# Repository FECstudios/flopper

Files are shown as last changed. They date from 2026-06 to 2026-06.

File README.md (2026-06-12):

# Flopper
**A physical study tracker that lives on your desk, not your phone.**



🎥 Demo: https://youtube.com/shorts/d5FyO_5jDAI

We built Flopper because we kept losing track of how long we actually studied vs. how long we *thought* we studied. It's a small 3D-printed device with an OLED screen, a rotary encoder, and an IMU sensor. Shake it to start a session, rotate the encoder to switch between modes (study, coding, break, etc.), and open a browser to see your stats on a dashboard the ESP32 hosts itself — no internet, no app, no account.

Three 14-year-olds from Turkey made this. It fits in your palm.

---

## Gallery

<p align="center">
  
  
  
</p>

---

## What it does

- Shake the device (or click the encoder) → session starts
- Rotate the encoder → switch activity mode
- Timer runs, buzzer goes off when time's up → shake again to dismiss
- Open `192.168.x.x` on any device on the same Wi-Fi → see your session history live

### Modes
Study · Coding · Reading · Break · Exercise · Free Time

---

## Hardware

| Component | What it's for |
|---|---|
| Seeed Studio XIAO ESP32-C6 | Runs everything, hosts the web server |
| MPU6050 (GY-521) | Detects shakes and tilts |
| 1.3" SH1106 OLED | Shows the current mode and timer |
| Rotary encoder | Scroll through modes, click to start |
| Buzzer | Alarm when session ends |
| 1S LiPo | Battery power |

---

## How it works

The MPU6050 constantly reads acceleration. When it detects a shake above a threshold, it starts the timer for whatever mode is selected. The rotary encoder lets you scroll through modes on the OLED before you start — or you can just click it instead of shaking if you want.

When the session ends, the buzzer fires. Shake or click to stop it.

The ESP32 runs a small web server over Wi-Fi. Once it connects to your network it shows its local IP on the OLED. Open that in a browser and you get a dashboard with your session history and time per mode.

---

## Setup

**You'll need:**
- Arduino IDE 2.x
- ESP32 board package
- Libraries: `Adafruit SH110X`, `MPU6050_light`, `ESPAsyncWebServer`

**Steps:**
1. Clone the repo
2. Open `flopper/codes/online.ino` or `flopper/codes/offline.ino`
3. Change the Wi-Fi credentials near the top if you prefer the online version:
   ```cpp
      const char* ssid = "YOUR_SSID";             
      const char* wifiPassword = "YOUR_PASSWORD"; 
   ```
4. Flash to XIAO ESP32-C6
5. IP address shows on the OLED once it connects — open it in a browser

---

## Why we made it

We wanted something physical. Every productivity app we tried was on the same device we were trying to avoid. With Flopper you just pick it up and shake it — that's the whole interaction. No screen to unlock, no notifications to scroll past.

Also we wanted to see if we could fit a display, motion sensor, encoder, Wi-Fi, and battery into something 3D-printed that actually looked decent.

---

## Roadmap

- [ ] Daily streaks
- [ ] Better analytics on the dashboard
- [ ] OTA updates
- [ ] Achievement system

---

## License

[Apache 2.0](LICENSE)

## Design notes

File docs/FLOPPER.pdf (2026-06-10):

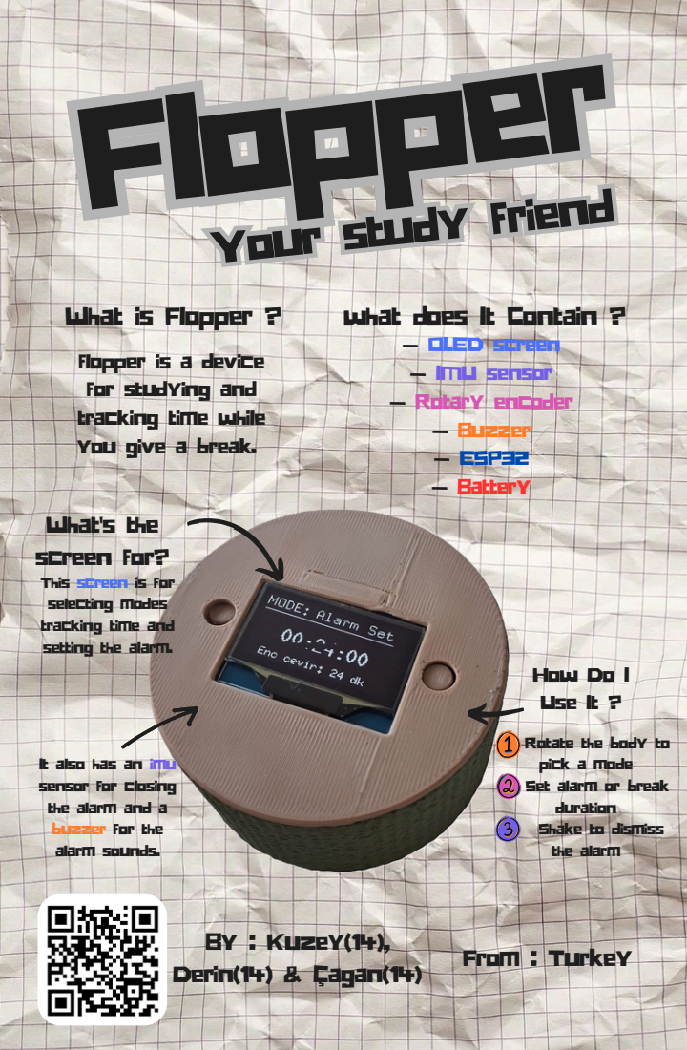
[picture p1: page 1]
By : Kuzey(14), Derin(14) & Çagan(14); From : Turkey; How Do I Use It ?

Flopper Flopper Flopper

Your study friend Your study friend Your study friend

What is Flopper ?

what does It Contain ?
— OLED screen
— IMU sensor
— Rotary encoder
— Buzzer
— ESP32
— Battery

flopper is a device
for studying and
tracking time while
you give a break.

What's the
screen for?
This screen is for
selecting modes
tracking time and
setting the alarm.

Rotate the body to
pick a mode
Set alarm or break
duration
Shake to dismiss
the alarm

It also has an imu
sensor for closing
the alarm and a
buzzer for the
alarm sounds.

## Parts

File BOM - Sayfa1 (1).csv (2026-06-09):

Part name | Quantity | Price | Link
XIAO ESP32C6 | 1 | 372,15TL | https://www.e-komponent.com/xiao-esp32c6-113991254
Buzzer | 1 | 8,83TL | https://www.robo90.com/pasif-buzzer-5v
Rotary Encoder Module | 1 | 36,70TL | https://www.robocombo.com/Arduino-Rotary-Encoder-Modulu
25x35 Lipo Battery | 1 | 699TL | https://www.trendyol.com/genel-markalar/25x35mm-lipo-pil-600mah-35x25mm-lipo-pil-602535-3-7v-lipo-pil-602535-3-7v-polimer-pil-bensu-pendik-p-824317653
1.3 inch oled screen | 1 | 152,30TL | https://www.voltaj.net/13-inch-i2c-oled-ekran-128x64-ssd1106g-pmu35378
MPU 6050 | 1 | 102,49TL | https://www.robitshop.com/urun/6-eksen-ivme-ve-gyro-sensoru-mpu6050-gy-521
M3 screw | 4 | 1,30TL | https://www.robotistan.com/m3-25mm-yildiz-basli-civata?language=tr&h=054a82bc
M3 hexnut | 1 | 10,80TL | https://www.robolinkmarket.com/m3-somun-10-adet

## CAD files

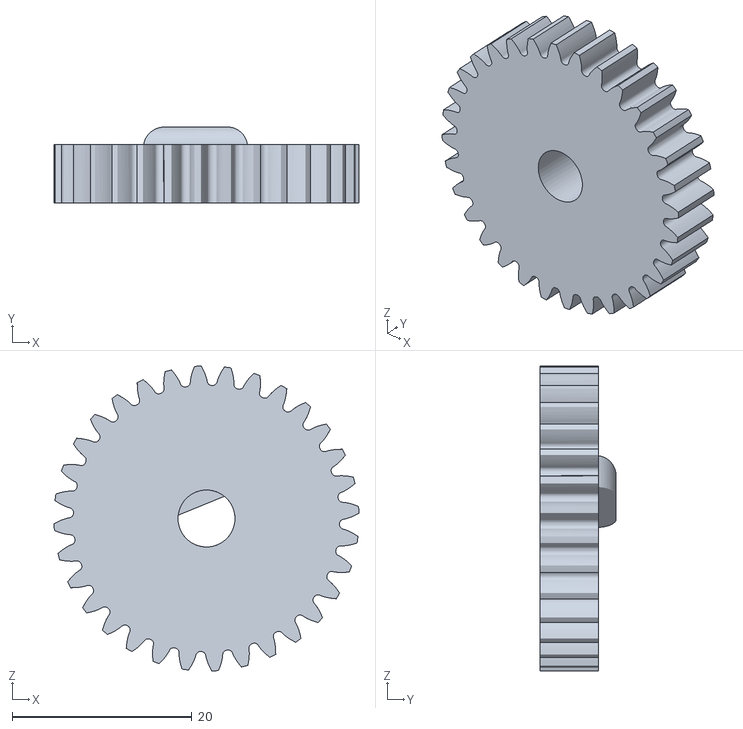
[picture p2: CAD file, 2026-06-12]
3dprintfiles/gear.stl
34.0 x 8.48 x 34.0

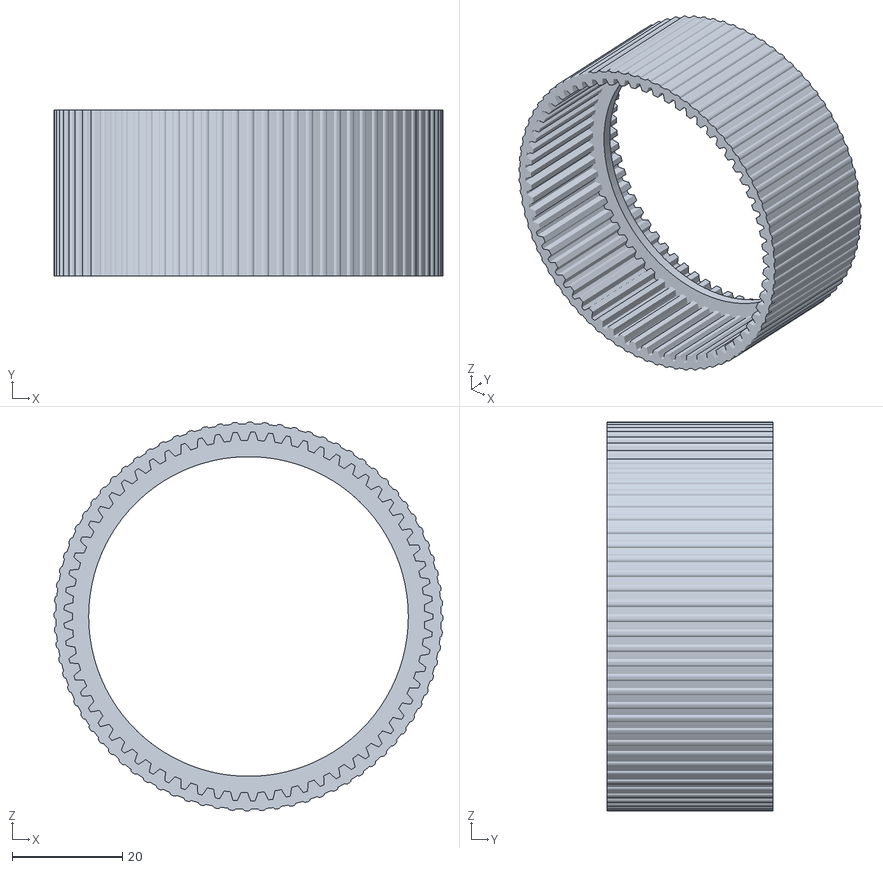
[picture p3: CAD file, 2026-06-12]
3dprintfiles/outter.stl
70.6 x 30.2 x 70.6

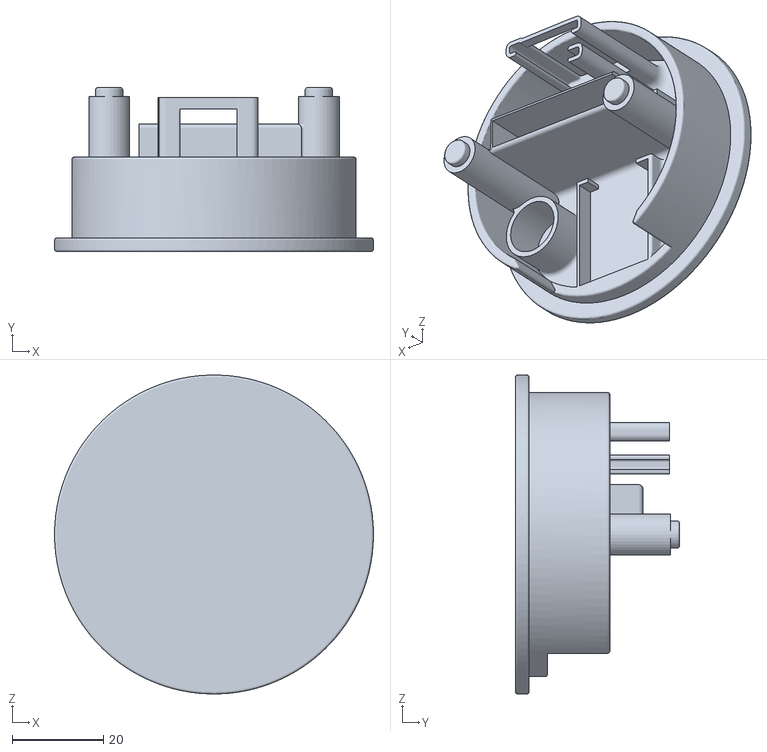
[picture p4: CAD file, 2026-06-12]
3dprintfiles/inner.stl
70.0 x 36.0 x 70.0

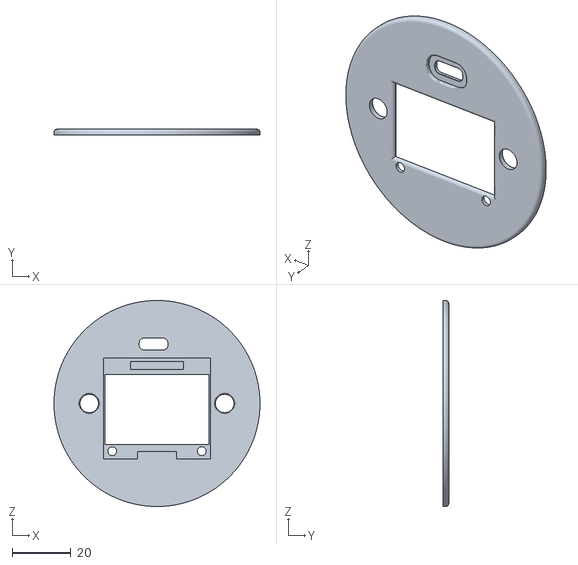
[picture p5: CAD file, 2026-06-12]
3dprintfiles/top.stl
70.0 x 1.90 x 70.0

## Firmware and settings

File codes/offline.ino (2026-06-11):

#include <U8g2lib.h>
#include <Wire.h>
#include <MPU6050_light.h>
#include <RotaryEncoder.h>
#include <Preferences.h>

MPU6050 mpu(Wire);
U8G2_SH1106_128X64_NONAME_F_HW_I2C u8g2(U8G2_R0, U8X8_PIN_NONE);

#define CLK_PIN D0 
#define DT_PIN  D1 

RotaryEncoder encoder(CLK_PIN, DT_PIN, RotaryEncoder::LatchMode::FOUR3);
Preferences preferences;

// --- Pomodoro Settings ---
int pomodoroWork = 25;
int pomodoroShortBreak = 5;
int pomodoroLongBreak = 15;
int pomodoroCycles = 4;

int currentPomodoroCycle = 1;
bool isPomodoroBreak = false;
long pomodoroRemainingSec = 25 * 60;
long pomodoroElapsedSec = 0;

// --- Time Tracking Variables ---
long totalStudySec = 0;      
long sessionStudySec = 0;    
long distractionSec = 0;     

long tytElapsedSec = 0;
long aytElapsedSec = 0;

// --- Other Global Variables ---
float accelX, accelY, accelZ;
float gyroX, gyroY, gyroZ;

int currentMode = 1;  
const char* modeNames[] = {"", "STUDY", "DISTRACT", "ALARM SET", "TYT EXAM", "AYT EXAM", "POMODORO", "STATISTICS"};

bool timerRunning = false;
bool alarmSetModeActive = false;  
bool tiltTriggered = false; 

unsigned long lastSecondTime = 0;
unsigned long lastTapTime = 0;
unsigned long lastShakeTime = 0; 
unsigned long lastSaveTime = 0;
unsigned long lastSetModeActivityTime = 0; 

// For factory reset via upside-down gesture
unsigned long upsideDownStartTime = 0;
bool isUpsideDown = false;

float tapThreshold = 1.9;  
float shakeThreshold = 3.0; 

int  alarmSetMinutes = 25;    
long alarmRemainingSec = 25 * 60;
long tytRemainingSec = 165 * 60;
long aytRemainingSec = 180 * 60;  
unsigned long lastScreenTime = 0;

// --- Function Prototypes ---
void calibrateSensors();
void readSensors();
void detectTap();
void detectTilt(); 
void detectShake(); 
void detectUpsideDownReset(); 
void updateTimers();
void drawPageDots();
void resetAllData(); 
String formatTime(long totalSeconds);

void setup() {
  Serial.begin(115200);  
  Wire.begin(22, 23);  
  u8g2.begin();
  
  pinMode(CLK_PIN, INPUT_PULLUP);
  pinMode(DT_PIN, INPUT_PULLUP);
  
  byte status = mpu.begin();
  if (status != 0) {
    while (1) {
      u8g2.clearBuffer();
      u8g2.setFont(u8g2_font_8x13_mr);
      u8g2.drawStr(0, 15, "NO SENSOR!");
      u8g2.sendBuffer();
      delay(1000);
    }
  }
  
  calibrateSensors();
  
  // Load data from persistent memory
  preferences.begin("study-data", true);
  totalStudySec = preferences.getULong("totalStudy", 0);
  distractionSec = preferences.getULong("distTime", 0); 
  tytElapsedSec = preferences.getULong("tytTime", 0);
  aytElapsedSec = preferences.getULong("aytTime", 0);
  pomodoroElapsedSec = preferences.getULong("pomTime", 0);
  pomodoroWork = preferences.getInt("pomWork", 25);
  pomodoroShortBreak = preferences.getInt("pomShort", 5);
  pomodoroLongBreak = preferences.getInt("pomLong", 15);
  pomodoroCycles = preferences.getInt("pomCycles", 4);
  preferences.end();
  
  sessionStudySec = 0; 
  
  pomodoroRemainingSec = pomodoroWork * 60;
  alarmRemainingSec = alarmSetMinutes * 60;
  
  delay(1000);
}

void loop() {
  readSensors();      
  detectTap(); 
  detectTilt(); 
  detectShake(); 
  detectUpsideDownReset(); 
  
  encoder.tick();
  int direction = (int)(encoder.getDirection());

  if (direction != 0) {
    if (timerRunning) {
      Serial.println("-> Timer is running! Mode cannot be changed.");
    }  
    else {
      if (currentMode == 3 && alarmSetModeActive) {
        if (direction < 0) alarmSetMinutes++;
        else alarmSetMinutes--;
        
        if (alarmSetMinutes < 1) alarmSetMinutes = 1;
        if (alarmSetMinutes > 180) alarmSetMinutes = 180;
        
        alarmRemainingSec = (long)alarmSetMinutes * 60;
        lastSetModeActivityTime = millis(); 
        
      } else {
        if (direction < 0) currentMode++;
        else currentMode--;
        
        if (currentMode < 1) currentMode = 1;
        if (currentMode > 7) currentMode = 7; 

        alarmSetModeActive = false;  
        Serial.print("-> New Mode: "); Serial.println(currentMode);
      }
    }
  }

  updateTimers();

  // Save to persistent memory every 60 seconds
  if (millis() - lastSaveTime > 60000) {
      lastSaveTime = millis();
      preferences.begin("study-data", false);
      preferences.putULong("totalStudy", totalStudySec);
      preferences.putULong("distTime", distractionSec); 
      preferences.putULong("tytTime", tytElapsedSec);
      preferences.putULong("aytTime", aytElapsedSec);
      preferences.putULong("pomTime", pomodoroElapsedSec);
      preferences.end();
  }

  // --- OLED DRAWING AREA ---
  if (millis() - lastScreenTime > 150) {
    lastScreenTime = millis();
    u8g2.clearBuffer();

    // 1. MODE NAME (Centered at the top, no uptime text anymore)
    u8g2.setFont(u8g2_font_8x13_mr);
    int textWidth = strlen(modeNames[currentMode]) * 8; 
    u8g2.drawStr((128 - textWidth) / 2, 10, modeNames[currentMode]);
    
    u8g2.drawLine(0, 16, 128, 16); 

    // 2. STATISTICS SCREEN (Mode 7)
    if (currentMode == 7) {
        u8g2.setFont(u8g2_font_6x10_tf);
        u8g2.drawStr(0, 30, "Total  :");
        u8g2.drawStr(70, 30, formatTime(totalStudySec).c_str());
        
        u8g2.drawStr(0, 40, "Distrct:");
        u8g2.drawStr(70, 40, formatTime(distractionSec).c_str());
        
        u8g2.drawStr(0, 50, "TYT    :");
        u8g2.drawStr(70, 50, formatTime(tytElapsedSec).c_str());
        
        u8g2.drawStr(0, 60, "AYT    :");
        u8g2.drawStr(70, 60, formatTime(aytElapsedSec).c_str());
        
        u8g2.sendBuffer();
        return; 
    }

    // 3. TIMER DISPLAY (Modes 1 to 6)
    long hours = 0, minutes = 0, seconds = 0;

    if (currentMode == 1) {  
      hours = sessionStudySec / 3600;
      minutes = (sessionStudySec % 3600) / 60;
      seconds = sessionStudySec % 60;
    }  
    else if (currentMode == 2) { 
      hours = distractionSec / 3600;
      minutes = (distractionSec % 3600) / 60;
      seconds = distractionSec % 60;
    }
    else if (currentMode == 3) {  
      hours = alarmRemainingSec / 3600;
      minutes = (alarmRemainingSec % 3600) / 60;
      seconds = alarmRemainingSec % 60;
    }
    else if (currentMode == 4) {  
      hours = tytRemainingSec / 3600;
      minutes = (tytRemainingSec % 3600) / 60;
      seconds = tytRemainingSec % 60;
    }
    else if (currentMode == 5) {  
      hours = aytRemainingSec / 3600;
      minutes = (aytRemainingSec % 3600) / 60;
      seconds = aytRemainingSec % 60;
    }
    else if (currentMode == 6) { 
      hours = pomodoroRemainingSec / 3600;
      minutes = (pomodoroRemainingSec % 3600) / 60;
      seconds = pomodoroRemainingSec % 60;
    }

    if (currentMode != 7) { 
      u8g2.setFont(u8g2_font_10x20_tn);  
      u8g2.setCursor(24, 40);
      
      if (hours < 10) u8g2.print("0"); u8g2.print(hours); u8g2.print(":");
      if (minutes < 10) u8g2.print("0"); u8g2.print(minutes); u8g2.print(":");
      if (seconds < 10) u8g2.print("0"); u8g2.print(seconds);
      
      u8g2.setFont(u8g2_font_6x10_tf);
      if (timerRunning) {
        if (currentMode == 6) {
            u8g2.drawStr(32, 55, isPomodoroBreak ? "[ BREAK ]" : "[ WORK ]");
        } else {
            u8g2.drawStr(32, 55, "[ RUNNING ]");
        }
      } else {
        if (currentMode == 3) {
          if (alarmSetModeActive) {
            u8g2.setCursor(10, 55);
            u8g2.print("[SET] "); u8g2.print(alarmSetMinutes); u8g2.print(" min");
          } else {
            u8g2.drawStr(0, 55, "Tilt:Set Shake:Reset"); 
          }
        } else if (currentMode == 6) {
            u8g2.drawStr(0, 55, "Tap:Start Shake:Reset"); 
        } else if (currentMode == 4 || currentMode == 5) {
            u8g2.drawStr(15, 55, "Shake -> Reset"); 
        } else if (currentMode == 1) {
            u8g2.drawStr(0, 55, "Tap:Start Shake:Reset Sess."); 
        } else if (currentMode == 2) {
            u8g2.drawStr(0, 55, "Tap:Start Shake:Reset Time"); 
        } else {
          u8g2.drawStr(35, 55, "[ PAUSED ]");
        }
      }
    }  

    drawPageDots();
    u8g2.sendBuffer();
  }
}

void drawPageDots() {
  u8g2.setFont(u8g2_font_6x10_tf);  
  int startX = 36; 
  int yCoord = 63;  

  for (int i = 1; i <= 7; i++) {
    u8g2.setCursor(startX + ((i - 1) * 9), yCoord);  
    if (i == currentMode) {
      u8g2.print((char)183);  
    } else {
      u8g2.print(".");  
    }
  }
}

void updateTimers() {
  if (timerRunning && (millis() - lastSecondTime >= 1000)) {
    lastSecondTime = millis();
    
    if (currentMode == 1) {
        sessionStudySec++;
        totalStudySec++; 
    }  
    else if (currentMode == 2) {
        distractionSec++; 
    }
    else if (currentMode == 3) {
      if (alarmRemainingSec > 0) alarmRemainingSec--;
      else timerRunning = false;  
    }
    else if (currentMode == 4) {
      if (tytRemainingSec > 0) {
          tytRemainingSec--;
          tytElapsedSec++;
      } else timerRunning = false;  
    }
    else if (currentMode == 5) {
      if (aytRemainingSec > 0) {
          aytRemainingSec--;
          aytElapsedSec++;
      } else timerRunning = false;  
    }
    else if (currentMode == 6) { 
        if (pomodoroRemainingSec > 0) {
            pomodoroRemainingSec--;
            pomodoroElapsedSec++;
        } else {
            if (isPomodoroBreak) {
                isPomodoroBreak = false;
                currentPomodoroCycle++;
                if (currentPomodoroCycle > pomodoroCycles) {
                    currentPomodoroCycle = 1; 
                    timerRunning = false;
                } else {
                    pomodoroRemainingSec = pomodoroWork * 60; 
                }
            } else {
                isPomodoroBreak = true;
                if (currentPomodoroCycle % pomodoroCycles == 0) {
                    pomodoroRemainingSec = pomodoroLongBreak * 60; 
                } else {
                    pomodoroRemainingSec = pomodoroShortBreak * 60; 
                }
            }
        }
    }
  }
}

void calibrateSensors() {
  u8g2.clearBuffer();
  u8g2.setFont(u8g2_font_8x13_mr);
  u8g2.drawStr(0, 15, "CALIBRATING...");
  u8g2.sendBuffer();
  delay(600);
  mpu.calcOffsets(true, true);  
  u8g2.clearBuffer();
  u8g2.drawStr(0, 15, "COMPLETE");
  u8g2.sendBuffer();
}

void readSensors() {
  mpu.update();
  accelX = mpu.getAccX();
  accelY = mpu.getAccY();
  accelZ = mpu.getAccZ();
  gyroX = mpu.getGyroX();
  gyroY = mpu.getGyroY();
  gyroZ = mpu.getGyroZ();
}

void detectTap() {
  float deviation = abs(accelZ - 1.0);
  if (deviation > tapThreshold) {
    if (millis() - lastTapTime > 600) {  
      timerRunning = !timerRunning;  
      lastTapTime = millis();
      lastSecondTime = millis();  
    }
  }
}

void detectTilt() {
  if (currentMode == 3 && !timerRunning) {
    float tiltMagnitude = abs(accelX) + abs(accelY);
    
    if (tiltMagnitude > 0.7) { 
      if (!tiltTriggered) {
        tiltTriggered = true;
        alarmSetModeActive = !alarmSetModeActive;
        lastSetModeActivityTime = millis(); 
      }
    } 
    else if (tiltMagnitude < 0.3) {
      tiltTriggered = false; 
    }

    if (alarmSetModeActive && (millis() - lastSetModeActivityTime > 5000)) {
      alarmSetModeActive = false;
      tiltTriggered = false; 
    }
  }
}

void detectShake() {
  if (currentMode == 1 || currentMode == 2 || currentMode == 3 || currentMode == 4 || currentMode == 5 || currentMode == 6) {
    float totalAccel = sqrt(accelX * accelX + accelY * accelY + accelZ * accelZ);
    
    if (totalAccel > shakeThreshold && (millis() - lastShakeTime > 1000)) {
      lastShakeTime = millis();
      
      if (currentMode == 1) sessionStudySec = 0; 
      else if (currentMode == 2) distractionSec = 0; 
      else if (currentMode == 3) {
        alarmRemainingSec = alarmSetMinutes * 60;
        timerRunning = false; 
      }
      else if (currentMode == 4) {
        tytRemainingSec = 165 * 60;
        timerRunning = false;
      }
      else if (currentMode == 5) {
        aytRemainingSec = 180 * 60;
        timerRunning = false;
      }
      else if (currentMode == 6) {
        pomodoroRemainingSec = pomodoroWork * 60;
        isPomodoroBreak = false;
        currentPomodoroCycle = 1;
        timerRunning = false;
      }
      Serial.println("-> SHAKE DETECTED! Current mode timer reset.");
    }
  }
}

void detectUpsideDownReset() {
  // Device is upside down when Z axis is approximately -1.0
  if (accelZ < -0.7) { 
    if (!isUpsideDown) {
      isUpsideDown = true;
      upsideDownStartTime = millis();
    } else {
      // If held upside down for 5 seconds (5000 ms)
      if (millis() - upsideDownStartTime > 5000) {
        resetAllData();
        isUpsideDown = false; // Reset trigger after action
      }
    }
  } else {
    isUpsideDown = false; // Cancel if device is righted
  }
}

void resetAllData() {
  // 1. Clear persistent memory
  preferences.begin("study-data", false);
  preferences.putULong("totalStudy", 0);
  preferences.putULong("distTime", 0);
  preferences.putULong("tytTime", 0);
  preferences.putULong("aytTime", 0);
  preferences.putULong("pomTime", 0);
  preferences.end();

  // 2. Reset live variables
  totalStudySec = 0;
  sessionStudySec = 0;
  distractionSec = 0;
  tytElapsedSec = 0;
  aytElapsedSec = 0;
  pomodoroElapsedSec = 0;
  
  pomodoroRemainingSec = pomodoroWork * 60;
  isPomodoroBreak = false;
  currentPomodoroCycle = 1;

  // 3. Show confirmation on screen
  u8g2.clearBuffer();
  u8g2.setFont(u8g2_font_8x13_mr);
  u8g2.drawStr(0, 25, "ALL DATA RESET!");
  u8g2.drawStr(0, 45, "FACTORY DEFAULT");
  u8g2.sendBuffer();
  delay(2000);
  
  Serial.println("-> ALL DATA RESET VIA UPSIDE-DOWN GESTURE");
}

String formatTime(long totalSeconds) {
  int h = totalSeconds / 3600;
  int m = (totalSeconds % 3600) / 60;
  int s = totalSeconds % 60;
  char buf[10];
  sprintf(buf, "%02d:%02d:%02d", h, m, s);
  return String(buf);
}

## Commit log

2026-06-09 Rename BOM - Sayfa1 (1).csv to BOM.csv
    [BOM.csv]
2026-06-12 Rename flopper.step to CAD /flopper.step
    [flopper.step]
2026-06-12 Update and rename BOM.csv to docs/BOM.csv
    [BOM.csv]
